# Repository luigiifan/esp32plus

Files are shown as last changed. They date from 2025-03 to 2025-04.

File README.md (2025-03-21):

# ESP32+ PROJECT

### I. Features
🔧 Fixes incorrect Boot Mode selection<br>
🔓 Compatible with <ins>ESP32 DevKit-V4 only</ins><br>
🔌 Stepdown Buck Converter MP1584 supports<br>
⚡ Includes 3.3V and 5V additional Power Expander<br>

### II. Technical Description
| Label  | Component  | I/O | Switchable | Description |
| :---: | :-----: | :---: | :-----: | ----- |
| S1 | Pushbutton | GPIO 34 |  | Parallel with pull-up 10K Resistor to 3.3V |
| S2 | Pushbutton | GPIO 35 |  | Parallel with pull-up 10K Resistor to 3.3V |
| L1 | 3mm LED | GPIO 17 | ✅ | Series 330 ohm Resistor for current limiter, Toggle switch (IV) to enable |
| L2 | 3mm LED | GPIO 16 | ✅ | Series 330 ohm Resistor for current limiter, Toggle switch (III) to enable |
| L3 | 3mm LED | GPIO 4 | ✅ | Series 330 ohm Resistor for current limiter, Toggle switch (II) to enable |
| L4 | 3mm LED | GPIO 2 | ✅ | Series 330 ohm Resistor for current limiter, Toggle switch (I) to enable |
| SG1 | Buzzer DC | GPIO 32 | ✅ | Place (B) jumper on pins 1-2 to enable |
| DISP | OLED 128x32 | GPIO 21 (SDA) <br> GPIO 22 (SCL) | ✅ | Place (D) jumper on pins 1-2 to enable |
| C1 | Polar Capacitor | EN | | Determine ESP32 to FLASH mode upon power-up |

### III. Schematic 
🔗 [Download PDF](https://github.com/user-attachments/files/19268394/esp32_plus.pdf)

### IV. 3D Model & Drawing
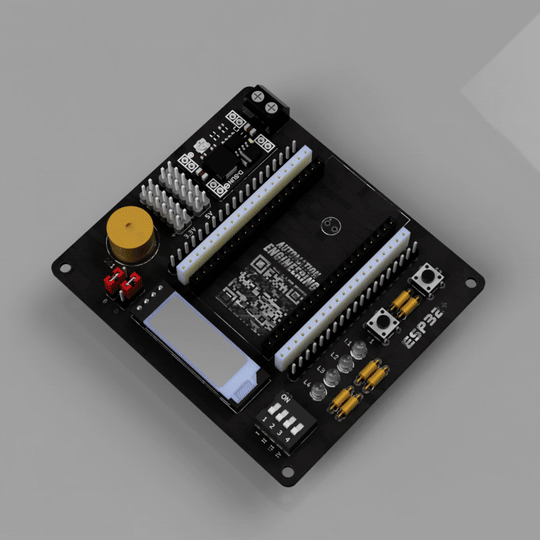
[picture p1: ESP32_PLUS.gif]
<p>
  
🔗 [Download PDF](https://github.com/user-attachments/files/19269748/ESP32_PLUS_DRAWING.pdf)

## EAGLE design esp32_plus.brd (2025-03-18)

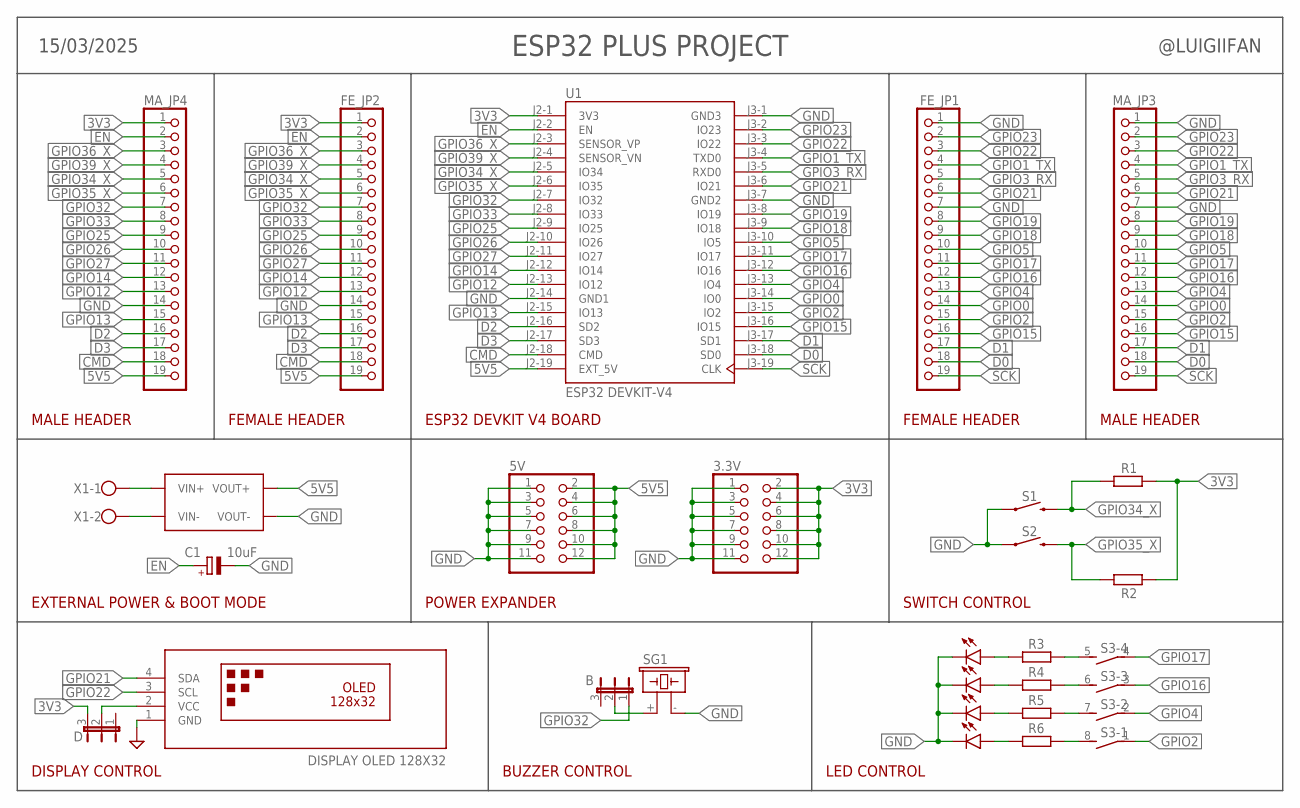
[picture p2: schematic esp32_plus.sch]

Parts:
3.3V, 5V: PINHD-2X6; 2X06
B: JP2E; JP2
C1: 10uF; E2,5-5
D: JP2E; JP2
FE_JP1, FE_JP2: PINHD-1X19; 1X19
L1, L2, L3, L4: LED3MM
MA_JP3, MA_JP4: PINHD-1X19; 1X19
MP1584: MP1584; DC-BRICK
R1, R2, R3, R4, R5, R6: R-EU_0207/10; 0207/10
S1, S2: MOMENTARY-SWITCH-SPST-PTH-6.0MM; TACTILE_SWITCH_PTH_6.0MM
S3: DS04E; DS-04
SG1: F/CM12P
U1: ESP32 DEVKIT-V4; MODULE_ESP32-DEVKITC-32D
U$1: DISPLAY OLED 128X32; DISPLAY-OLED-128X32
X1: W237-102

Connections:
3V3: 3.3V.2, 3.3V.4, 3.3V.6, 3.3V.8, 3.3V.10, 3.3V.12, D.3, FE_JP2.1, MA_JP4.1, R1.2, R2.2, U1.J2-1 (3V3)
5V5: 5V.2, 5V.4, 5V.6, 5V.8, 5V.10, 5V.12, FE_JP2.19, MA_JP4.19, MP1584.OUT1+ (VOUT+), MP1584.OUT2+ (VOUT+), U1.J2-19 (EXT_5V)
CMD: FE_JP2.18, MA_JP4.18, U1.J2-18 (CMD)
D0: FE_JP1.18, MA_JP3.18, U1.J3-18 (SD0)
D1: FE_JP1.17, MA_JP3.17, U1.J3-17 (SD1)
D2: FE_JP2.16, MA_JP4.16, U1.J2-16 (SD2)
D3: FE_JP2.17, MA_JP4.17, U1.J2-17 (SD3)
EN: C1.+, FE_JP2.2, MA_JP4.2, U1.J2-2 (EN)
GND: 3.3V.1, 3.3V.3, 3.3V.5, 3.3V.7, 3.3V.9, 3.3V.11, 5V.1, 5V.3, 5V.5, 5V.7, 5V.9, 5V.11, C1.-, FE_JP1.1, FE_JP1.7, FE_JP2.14, L1.K (C), L2.K (C), L3.K (C), L4.K (C), MA_JP3.1, MA_JP3.7, MA_JP4.14, MP1584.OUT1- (VOUT-), MP1584.OUT2- (VOUT-), S1.1, S2.1, SG1.- (2), U1.J2-14 (GND1), U1.J3-1 (GND3), U1.J3-7 (GND2), U$1.1 (GND)
GPIO0: FE_JP1.14, MA_JP3.14, U1.J3-14 (IO0)
GPIO1_TX: FE_JP1.4, MA_JP3.4, U1.J3-4 (TXD0)
GPIO2: FE_JP1.15, MA_JP3.15, S3.1, U1.J3-15 (IO2)
GPIO3_RX: FE_JP1.5, MA_JP3.5, U1.J3-5 (RXD0)
GPIO4: FE_JP1.13, MA_JP3.13, S3.2 (1), U1.J3-13 (IO4)
GPIO5: FE_JP1.10, MA_JP3.10, U1.J3-10 (IO5)
GPIO12: FE_JP2.13, MA_JP4.13, U1.J2-13 (IO12)
GPIO13: FE_JP2.15, MA_JP4.15, U1.J2-15 (IO13)
GPIO14: FE_JP2.12, MA_JP4.12, U1.J2-12 (IO14)
GPIO15: FE_JP1.16, MA_JP3.16, U1.J3-16 (IO15)
GPIO16: FE_JP1.12, MA_JP3.12, S3.3 (1), U1.J3-12 (IO16)
GPIO17: FE_JP1.11, MA_JP3.11, S3.4 (1), U1.J3-11 (IO17)
GPIO18: FE_JP1.9, MA_JP3.9, U1.J3-9 (IO18)
GPIO19: FE_JP1.8, MA_JP3.8, U1.J3-8 (IO19)
GPIO21: FE_JP1.6, MA_JP3.6, U1.J3-6 (IO21), U$1.4 (SDA)
GPIO22: FE_JP1.3, MA_JP3.3, U1.J3-3 (IO22), U$1.3 (SCL)
GPIO23: FE_JP1.2, MA_JP3.2, U1.J3-2 (IO23)
GPIO25: FE_JP2.9, MA_JP4.9, U1.J2-9 (IO25)
GPIO26: FE_JP2.10, MA_JP4.10, U1.J2-10 (IO26)
GPIO27: FE_JP2.11, MA_JP4.11, U1.J2-11 (IO27)
GPIO32: B.1, FE_JP2.7, MA_JP4.7, U1.J2-7 (IO32)
GPIO33: FE_JP2.8, MA_JP4.8, U1.J2-8 (IO33)
GPIO34_X: FE_JP2.5, MA_JP4.5, R1.1, S1.4 (2), U1.J2-5 (IO34)
GPIO35_X: FE_JP2.6, MA_JP4.6, R2.1, S2.4 (2), U1.J2-6 (IO35)
GPIO36_X: FE_JP2.3, MA_JP4.3, U1.J2-3 (SENSOR_VP)
GPIO39_X: FE_JP2.4, MA_JP4.4, U1.J2-4 (SENSOR_VN)
unnamed: D.2, U$1.2 (VCC)
unnamed: R4.2, S3.6 (2)
unnamed: R5.2, S3.7 (2)
unnamed: R6.2, S3.8 (2)
unnamed: R3.2, S3.5 (2)
unnamed: B.2, SG1.+ (1)
unnamed: L1.A, R3.1
unnamed: L2.A, R4.1
unnamed: L3.A, R5.1
unnamed: L4.A, R6.1
unnamed: MP1584.IN1+ (VIN+), MP1584.IN2+ (VIN+), X1.1
unnamed: MP1584.IN1- (VIN-), MP1584.IN2- (VIN-), X1.2
SCK: FE_JP1.19, MA_JP3.19, U1.J3-19 (CLK)

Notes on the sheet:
ESP32 DEVKIT V4 BOARD
FEMALE HEADER
MALE HEADER
ESP32 PLUS PROJECT
EXTERNAL POWER & BOOT MODE
POWER EXPANDER
SWITCH CONTROL
DISPLAY CONTROL
BUZZER CONTROL
LED CONTROL
15/03/2025
@LUIGIIFAN

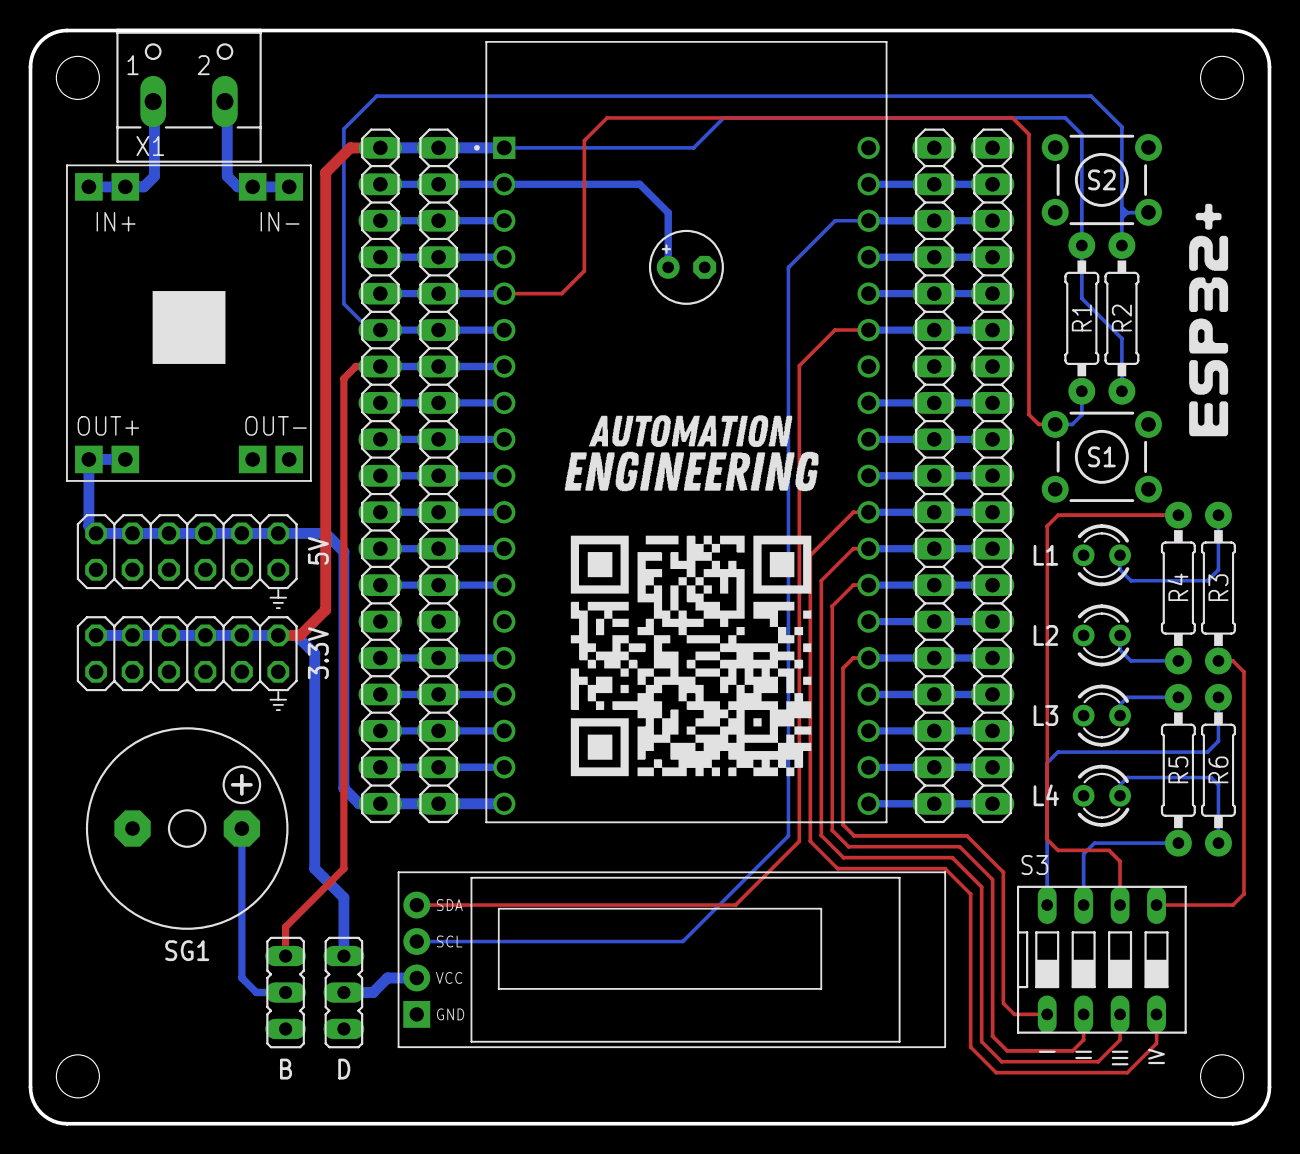
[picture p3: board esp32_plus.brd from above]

Board: 2 copper layers, 86.4 x 76.2 mm, 27 parts (0 on the bottom side), 48 nets.

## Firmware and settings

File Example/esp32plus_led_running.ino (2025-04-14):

#include <SPI.h>
#include <Wire.h>
#include <Adafruit_GFX.h>
#include <Adafruit_SSD1306.h>

#define SCREEN_WIDTH 128
#define SCREEN_HEIGHT 32
#define SCREEN_ADDRESS 0x3C
#define OLED_RESET     -1
#define BUZZER 32
#define S1 34
#define S2 35

Adafruit_SSD1306 display(SCREEN_WIDTH, SCREEN_HEIGHT, &Wire, OLED_RESET);

int led[] = {17, 16, 4, 2};
bool is_running;
bool is_done;
unsigned long previousMillis = 0;
unsigned long interval = 100; 
int counter;

void showDisplay(){
  display.clearDisplay();
  display.setTextColor(1);
  display.setTextWrap(false);
  display.setCursor(59, 12);
  display.print(counter);
  display.setCursor(9, 12);
  display.print("Counter:");
  display.display();
}

void setup() {
  Serial.begin(9600);
  display.begin(SSD1306_SWITCHCAPVCC, SCREEN_ADDRESS);
  display.display();
  display.clearDisplay();
  for(int i=0; i <= 3; i++){
    pinMode(led[i], OUTPUT);
  }
  pinMode(BUZZER, OUTPUT);
  pinMode(S1, INPUT);
  pinMode(S2, INPUT);
}

void loop() {
  if(digitalRead(S1) == LOW){
    is_running = true;
    Serial.println("S1 pressed!");
  }
  if(digitalRead(S2) == LOW){
    is_running = false;
    Serial.println("S2 pressed!");
  }

  if(is_running == true){
    unsigned long currentMillis = millis();

    if (currentMillis - previousMillis >= interval) {
      previousMillis = currentMillis;

      static int ledIndex = 0;
      if(ledIndex >= 0 && is_done == false){
        digitalWrite(led[ledIndex], HIGH);
        ledIndex++;
      }

      if(ledIndex > 3 && is_done == false){
        digitalWrite(BUZZER, HIGH);
        delay(100);
        digitalWrite(BUZZER, LOW);
        counter++;
        is_done = true;
      }

      if (ledIndex <= 4 && is_done == true) {
        digitalWrite(led[ledIndex], LOW);
        ledIndex--;
      }

      if(ledIndex < 0 && is_done == true){
        is_done = false;
        ledIndex = 0;
      }
    }
  }
  showDisplay();
}

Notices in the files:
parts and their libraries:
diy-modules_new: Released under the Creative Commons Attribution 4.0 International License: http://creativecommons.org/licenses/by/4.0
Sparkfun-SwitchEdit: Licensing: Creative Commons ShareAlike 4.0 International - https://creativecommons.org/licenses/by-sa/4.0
